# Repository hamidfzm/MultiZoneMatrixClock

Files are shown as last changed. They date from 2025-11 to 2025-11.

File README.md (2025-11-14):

# Multi-Zone Matrix Clock

A WiFi-enabled LED matrix clock for ESP8266 that displays time from multiple timezones. Features automatic NTP synchronization, DST handling, and a web-based configuration interface.

 

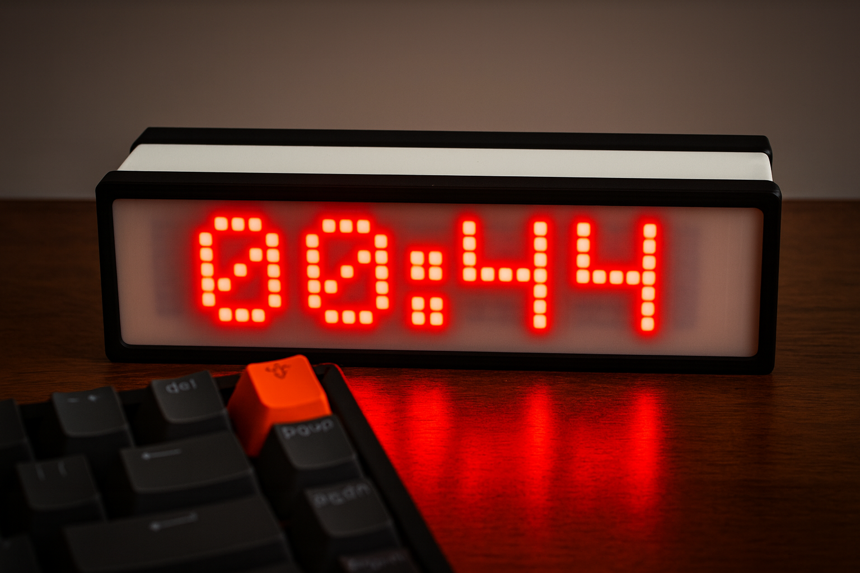
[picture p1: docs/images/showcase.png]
Showcase


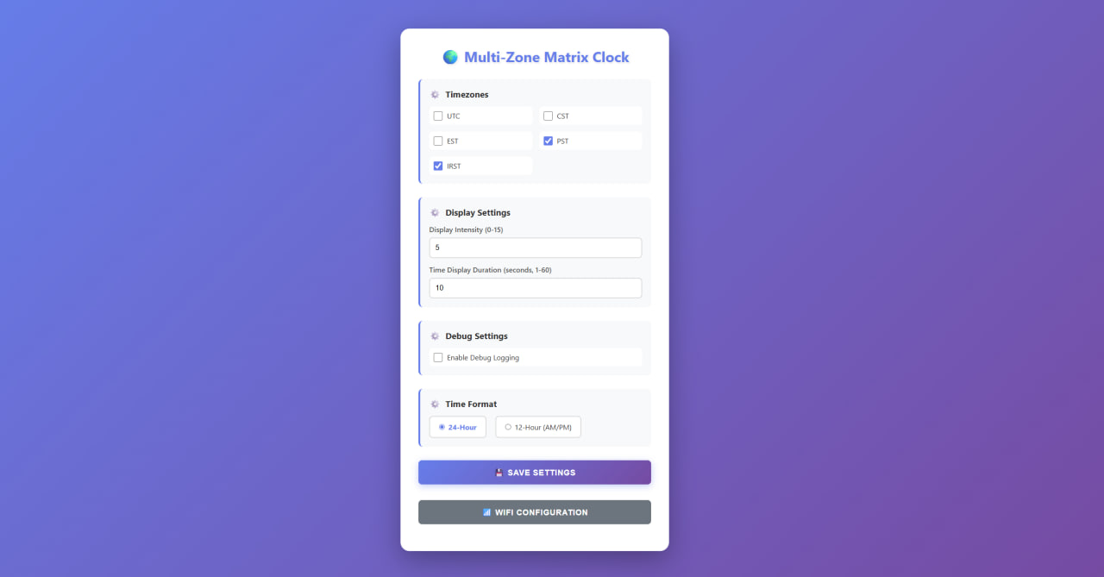
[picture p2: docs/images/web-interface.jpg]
Web Interface


## Features

- 🌍 **Multiple Timezone Support**: Display time from up to 6 different timezones (UTC, CST, EST, PST, IRST, and more)
- ⏰ **Automatic Time Sync**: NTP synchronization ensures accurate time
- 🌅 **DST Handling**: Automatic Daylight Saving Time adjustments for US timezones
- 📱 **Web Configuration**: Easy-to-use web interface for settings
- 🔌 **WiFi Manager**: Automatic WiFi configuration portal on first boot
- 🎨 **Customizable Display**: Adjustable brightness and 12/24-hour format
- 📺 **Animated Display**: Smooth scrolling animations for timezone names and time
- 💾 **Persistent Settings**: Settings saved to EEPROM

## Hardware Requirements

- **ESP8266** (NodeMCU, Wemos D1 Mini, or similar)
- **MAX7219 LED Matrix Display** (4 modules, FC16 hardware type)
- **Jumper wires** for connections
- **5V power supply** (USB or external adapter)

### Pin Connections

| ESP8266 Pin | MAX7219 Pin | Description |
|---|---|---|
| D5 | CLK | Clock |
| D7 | DIN | Data In |
| D8 | CS | Chip Select |
| 5V | VCC | Power |
| GND | GND | Ground |

> **Note**: The pin definitions can be modified in `config.h` if needed.

## 3D Printing

This project includes 3MF files for 3D printing the enclosure and mounting components. All files are optimized for **Bambu Lab A1 Mini** and are located in the `stl/` directory.

### Available 3MF Files

| File | Description |
|---|---|
| `FRONT.3mf` | Front panel/enclosure |
| `FRONT Wemos D1 Mini.3mf` | Front panel with Wemos D1 Mini mounting |
| `BACK.3mf` | Back panel/enclosure |
| `FRAME FRONT.3mf` | Front frame component |
| `FRAME BACK.3mf` | Back frame component |
| `2 x MATRIX HOLDER.3mf` | Matrix display holder (print 2x) |

### Printing Instructions for Bambu Lab A1 Mini

1. **Open files in Bambu Studio** (or compatible slicer)
2. **Recommended settings**:
   - **Layer height**: 0.2mm (standard quality) or 0.16mm (fine quality)
   - **Infill**: 15-20% (sufficient for structural integrity)
   - **Supports**: Enable if needed (check model orientation)
   - **Material**: PLA or PETG recommended
3. **Print order**:
   - Start with the frame components (`FRAME FRONT.3mf`, `FRAME BACK.3mf`)
   - Print the front and back panels
   - Print 2x of the matrix holder
4. **Assembly**: Follow the component names to assemble the enclosure

### Notes

- All files are provided in 3MF format for easy import into Bambu Studio
- The models are designed to fit standard MAX7219 8x8 LED matrix modules
- Ensure proper clearance for the ESP8266 board and wiring
- You may need to adjust print settings based on your specific material and preferences

## Software Requirements

### Arduino IDE Libraries

Install the following libraries via Arduino IDE Library Manager:

1. **ESP8266WiFi** (included with ESP8266 board support)
2. **WiFiManager** by tzapu - [GitHub](https://github.com/tzapu/WiFiManager)
3. **MD_Parola** by majicDesigns - [GitHub](https://github.com/MajicDesigns/MD_Parola)
4. **MD_MAX72XX** by majicDesigns - [GitHub](https://github.com/MajicDesigns/MD_MAX72XX)
5. **NTPClient** by Fabrice Weinberg - [GitHub](https://github.com/arduino-libraries/NTPClient)
6. **WiFiUdp** (included with ESP8266 board support)
7. **EEPROM** (included with ESP8266 board support)

### Arduino IDE Setup

1. Install **Arduino IDE** (1.8.x or newer)
2. Add ESP8266 board support:
   - Go to `File` → `Preferences`
   - Add to Additional Board Manager URLs: `http://arduino.esp8266.com/stable/package_esp8266com_index.json`
   - Go to `Tools` → `Board` → `Boards Manager`
   - Search for "ESP8266" and install
3. Select your board: `Tools` → `Board` → `ESP8266 Boards` → `NodeMCU 1.0 (ESP-12E Module)` (or your specific board)
4. Set upload speed to `115200` in `Tools` → `Upload Speed`

## Installation

1. **Clone or download** this repository
2. **Open** `MultiZoneMatrixClock.ino` in Arduino IDE
3. **Install required libraries** (see Software Requirements above)
4. **Connect your hardware** according to the pin connections table
5. **Select your ESP8266 board** and COM port in Arduino IDE
6. **Upload** the sketch to your ESP8266

## First Time Setup

1. **Power on** the ESP8266
2. **Connect to WiFi**: The device will create a WiFi access point named `MultiZoneClock`
3. **Connect** to this network with your phone/computer
4. **Configure WiFi**: A portal will automatically open (or navigate to `192.168.4.1`)
5. **Enter your WiFi credentials** and connect
6. **Note the IP address** displayed in Serial Monitor (or check your router's connected devices)
7. **Access the web interface** by navigating to the IP address in your browser

## Configuration

### Web Interface

Access the web configuration interface by navigating to your ESP8266's IP address in a web browser.

**Settings available:**
- **Timezones**: Enable/disable which timezones to display
- **Display Intensity**: Adjust brightness (0-15)
- **Time Format**: Choose between 12-hour (AM/PM) or 24-hour format
- **WiFi Configuration**: Reconfigure WiFi connection

### Default Settings

- **Enabled Timezones**: EST, IRST
- **Display Intensity**: 5
- **Time Format**: 24-hour
- **Time Display Duration**: 10 seconds per timezone

### Manual Configuration

You can modify default settings in the code:

- **Timezones**: Edit `timezone.cpp` to add/modify timezones
- **Hardware pins**: Edit `config.h` to change pin assignments
- **Display settings**: Edit `config.h` for timing and display parameters

## Usage

### Display Behavior

- **Single Timezone Mode**: If only one timezone is enabled, the clock displays time statically with a blinking colon
- **Multiple Timezone Mode**: If multiple timezones are enabled:
  1. Timezone name scrolls up
  2. Brief pause
  3. Time scrolls in from left
  4. Time scrolls out to right
  5. Repeats for next enabled timezone

### Time Synchronization

- The clock automatically syncs with NTP servers (`pool.ntp.org`)
- Sync occurs periodically to maintain accuracy
- DST is automatically calculated and applied for US timezones

## Project Structure

```
MultiZoneMatrixClock/
├── MultiZoneMatrixClock.ino  # Main Arduino sketch
├── config.h                   # Configuration constants and settings structure
├── display.h                  # Display manager header
├── display.cpp                # Display manager implementation
├── timezone.h                  # Timezone manager header
├── timezone.cpp                # Timezone manager implementation
├── webserver.h                 # Web server manager header
├── webserver.cpp               # Web server manager implementation
├── stl/                        # 3D printing files (3MF format)
│   ├── FRONT.3mf
│   ├── FRONT Wemos D1 Mini.3mf
│   ├── BACK.3mf
│   ├── FRAME FRONT.3mf
│   ├── FRAME BACK.3mf
│   └── 2 x MATRIX HOLDER.3mf
└── README.md                   # This file
```

## Troubleshooting

### WiFi Connection Issues

- **Can't connect to AP**: Reset the device and try again
- **Portal doesn't open**: Manually navigate to `192.168.4.1`
- **Can't find device IP**: Check Serial Monitor output or your router's device list

### Display Issues

- **No display**: Check wiring connections, especially power and ground
- **Garbled text**: Verify pin connections match `config.h`
- **Too dim/bright**: Adjust intensity in web interface (0-15)

### Time Issues

- **Wrong time**: Ensure WiFi is connected and NTP sync is working
- **DST not working**: Check that timezone uses DST in `timezone.cpp`
- **Timezone offset wrong**: Verify timezone offset in `timezone.cpp`

### Serial Monitor

Enable Serial Monitor at `115200` baud to see debug information:
- WiFi connection status
- IP address
- NTP sync status
- Display state changes

## Customization

### Adding New Timezones

Edit `timezone.cpp`:

```cpp
// Add to timezones array
timezones[5] = {"TZNAME", offset_seconds, uses_dst};
```

Update `TZ_COUNT` in `config.h` if adding more than 6 timezones.

### Changing Display Hardware

Modify `config.h`:
- `HARDWARE_TYPE`: Change if using different MAX7219 module type
- `MAX_DEVICES`: Number of matrix modules
- Pin definitions: `CLK_PIN`, `DATA_PIN`, `CS_PIN`

## Technical Details

- **MCU**: ESP8266 (80MHz, 4MB Flash)
- **Display**: MAX7219 8x8 LED Matrix (4 modules = 32x8 display)
- **Protocol**: SPI for display communication
- **Storage**: EEPROM for settings persistence
- **Network**: WiFi 802.11 b/g/n
- **Time Protocol**: NTP (Network Time Protocol)

## License

This project is open source. Feel free to modify and distribute.

## Contributing

Contributions are welcome! Please feel free to submit a Pull Request.

## Acknowledgments

- Built with Arduino IDE and ESP8266
- Uses excellent libraries from the Arduino community
- Inspired by the need for a simple, multi-timezone clock

## Support

For issues, questions, or contributions, please open an issue on GitHub.

---

**Enjoy your Multi-Zone Matrix Clock!** ⏰🌍

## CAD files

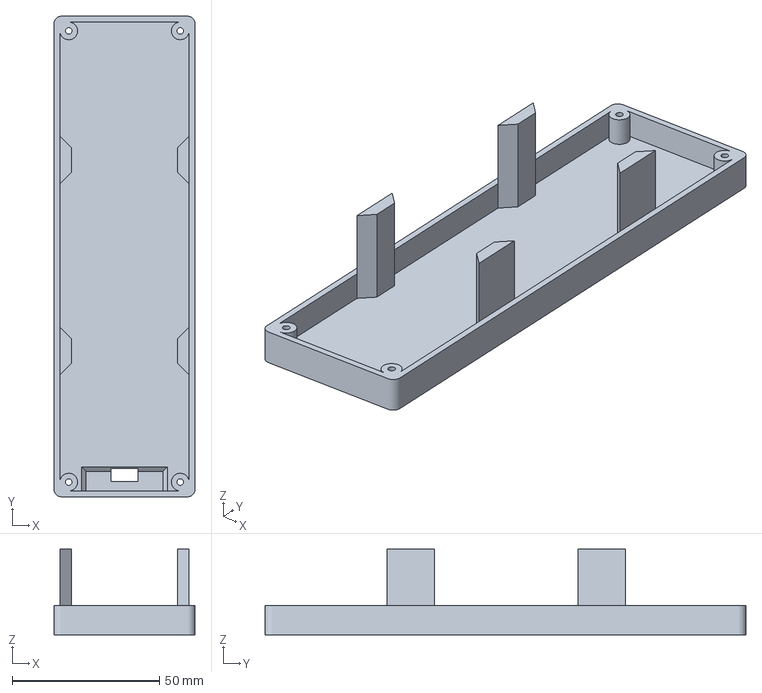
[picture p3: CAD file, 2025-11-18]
stl/BACK Wemos D1 Mini.3mf
47.8 x 162.9 x 29.0 mm

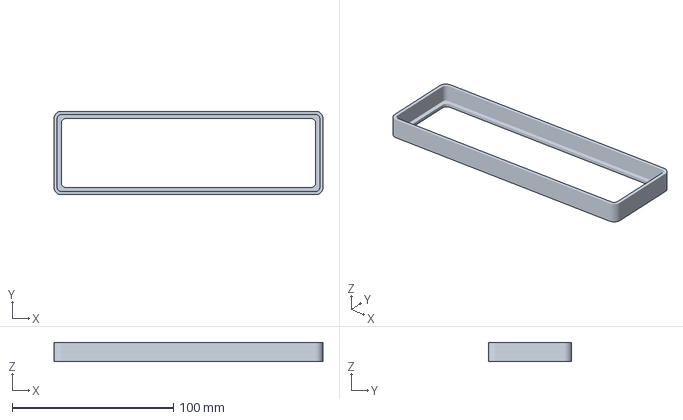
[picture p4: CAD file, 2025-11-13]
stl/FRAME FRONT.3mf
166.9 x 51.8 x 12.0 mm

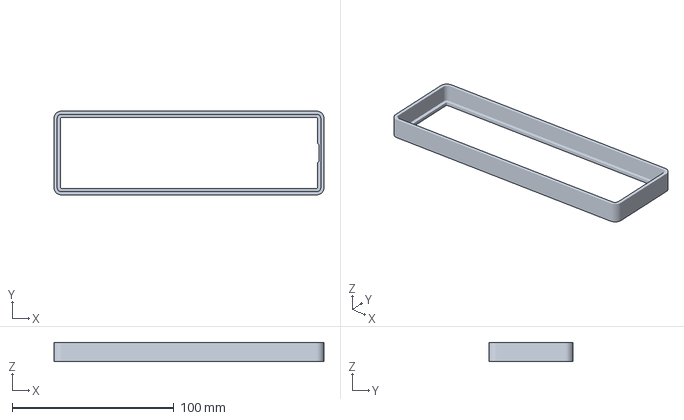
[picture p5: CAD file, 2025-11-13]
stl/FRAME BACK.3mf
166.9 x 51.8 x 12.0 mm

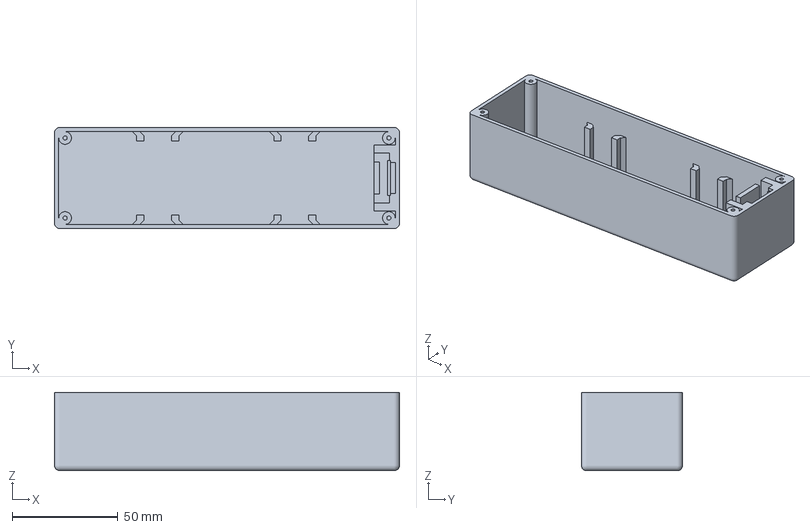
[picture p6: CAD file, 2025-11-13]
stl/FRONT.3mf
162.9 x 47.8 x 37.0 mm

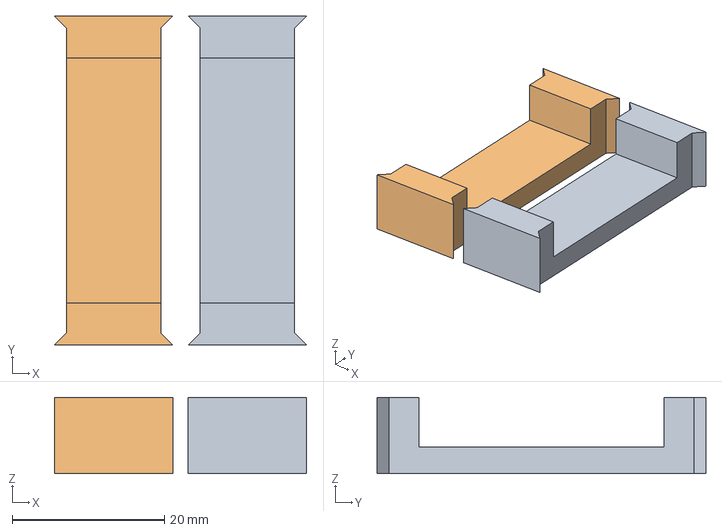
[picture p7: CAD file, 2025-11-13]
stl/2 x MATRIX HOLDER.3mf
33.1 x 43.2 x 10.0 mm
MATRIX HOLDER x 2

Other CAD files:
stl/BACK.3mf
stl/FRONT Wemos D1 Mini.3mf

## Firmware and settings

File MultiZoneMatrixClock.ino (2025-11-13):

#include <ESP8266WiFi.h>
#include <WiFiManager.h>
#include <ESP8266WebServer.h>
#include <WiFiUdp.h>
#include <NTPClient.h>
#include <EEPROM.h>
#include <time.h>

#include "config.h"
#include "timezone.h"
#include "display.h"
#include "webserver.h"

// Global objects
WiFiUDP ntpUDP;
NTPClient timeClient(ntpUDP, "pool.ntp.org");
ESP8266WebServer server(80);

TimezoneManager tzManager;
DisplayManager displayManager;
Settings settings;
WebServerManager webManager(&server, &tzManager, &settings, &displayManager);

void saveSettings() {
  settings.magic = EEPROM_MAGIC;
  for (int i = 0; i < TZ_COUNT; i++) {
    settings.enabled[i] = tzManager.tzEnabled[i] ? 1 : 0;
  }
  EEPROM.put(0, settings);
  EEPROM.commit();
}

void loadSettings() {
  EEPROM.get(0, settings);
  if (settings.magic != EEPROM_MAGIC) {
    // Default settings
    settings.intensity = 5;
    settings.use12Hour = 0;
    settings.debugEnabled = 0;
    settings.timeDisplayDuration = 10; // Default 10 seconds
    for (int i = 0; i < TZ_COUNT; i++) {
      settings.enabled[i] = tzManager.tzEnabled[i] ? 1 : 0;
    }
    saveSettings();
  } else {
    // Load enabled timezones from EEPROM
    for (int i = 0; i < TZ_COUNT; i++) {
      tzManager.tzEnabled[i] = settings.enabled[i] != 0;
    }
    // Initialize defaults for new fields if they're 0 (first time loading after update)
    if (settings.timeDisplayDuration == 0) {
      settings.timeDisplayDuration = 10;
    }
  }
  // Update display manager with time display duration
  displayManager.setTimeDisplayDuration(settings.timeDisplayDuration * 1000); // Convert to milliseconds
}

String getShortTime() {
  String full = timeClient.getFormattedTime(); // HH:MM:SS
  String hh = full.substring(0, 2);
  String mm = full.substring(3, 5);
  int hour = hh.toInt();
  int minute = mm.toInt();
  
  if (settings.use12Hour) {
    bool isPM = hour >= 12;
    hour = hour % 12;
    if (hour == 0) hour = 12;
    // Format with zero padding
    String hourStr = hour < 10 ? "0" + String(hour) : String(hour);
    String minuteStr = minute < 10 ? "0" + String(minute) : String(minute);
    return hourStr + ":" + minuteStr + (isPM ? " PM" : " AM");
  } else {
    // Already padded from getFormattedTime, but ensure it's correct
    return hh + ":" + mm;
  }
}

void setup() {
  Serial.begin(115200);
  delay(1000);
  
  // Initialize EEPROM
  EEPROM.begin(EEPROM_SIZE);
  
  // Initialize timezone manager
  tzManager.init();
  
  // Load settings from EEPROM (this will initialize debug flag)
  loadSettings();
  
  // Only log if debug is enabled
  if (settings.debugEnabled) {
    Serial.println("Multi-Zone Matrix Clock Starting...");
  }
  
  // Initialize display
  displayManager.begin(settings.intensity);
  displayManager.setShowTimezone(tzManager.getEnabledCount() > 1);
  
  // Connect to WiFi
  WiFiManager wm;
  wm.autoConnect("MultiZoneClock");
  
  if (settings.debugEnabled) {
    Serial.print("Connected! IP address: ");
    Serial.println(WiFi.localIP());
  }
  
  // Initialize NTP client
  timeClient.begin();
  
  // Find first enabled timezone
  int firstTZ = tzManager.nextEnabledTZ(-1);
  if (firstTZ >= 0) {
    displayManager.setCurrentTZ(firstTZ);
    long offset = tzManager.getCurrentOffset(firstTZ);
    timeClient.setTimeOffset(offset);
  }
  
  // Initialize web server
  webManager.begin();
  
  // Start with first timezone display
  int enabledCount = tzManager.getEnabledCount();
  if (enabledCount > 0) {
    if (enabledCount > 1 && displayManager.shouldShowTimezone()) {
      displayManager.setState(SHOW_TZ_SCROLL);
      String tzName = String(tzManager.getTimezoneName(firstTZ));
      displayManager.setTimezoneName(tzName); // This will start the scroll
    } else {
      // Single timezone mode - go straight to time
      String timeStr = getShortTime();
      displayManager.setTimeString(timeStr);
      displayManager.setState(SHOW_TIME_STATIC);
    }
  }
  
  if (settings.debugEnabled) {
    Serial.println("Setup complete!");
  }
}

void loop() {
  server.handleClient();
  
  // Update NTP client periodically (it's smart enough to only sync when needed)
  static unsigned long lastNTPUpdate = 0;
  if (millis() - lastNTPUpdate >= NTP_UPDATE_INTERVAL) {
    timeClient.update();
    lastNTPUpdate = millis();
  }
  
  // Update time offset only when timezone changes (for DST and timezone switching)
  static int lastTZ = -1;
  int currentTZ = displayManager.getCurrentTZ();
  if (currentTZ != lastTZ) {
    long currentOffset = tzManager.getCurrentOffset(currentTZ);
    timeClient.setTimeOffset(currentOffset);
    lastTZ = currentTZ;
  }
  
  DisplayState state = displayManager.getState();
  
  switch (state) {
    case SHOW_TZ_SCROLL:
      displayManager.update();
      if (displayManager.getState() == SHOW_TZ_WAIT) {
        // Prepare time string
        String timeStr = getShortTime();
        displayManager.setTimeString(timeStr);
      }
      break;
      
    case SHOW_TZ_WAIT:
      displayManager.update();
      break;
      
    case SHOW_TIME_LTR:
      displayManager.update();
      break;
      
    case SHOW_TIME_RTL:
      displayManager.update();
      if (displayManager.getState() == SHOW_TZ_SCROLL) {
        // Move to next timezone
        int nextTZ = tzManager.nextEnabledTZ(currentTZ);
        displayManager.setCurrentTZ(nextTZ);
        
        // Update timezone display setting based on count
        int enabledCount = tzManager.getEnabledCount();
        displayManager.setShowTimezone(enabledCount > 1);
        
        if (displayManager.shouldShowTimezone()) {
          String tzName = String(tzManager.getTimezoneName(nextTZ));
          displayManager.setTimezoneName(tzName);
        } else {
          // Single timezone mode - skip timezone name, go straight to time
          displayManager.setTimezoneName("");
          String timeStr = getShortTime();
          displayManager.setTimeString(timeStr);
          displayManager.setState(SHOW_TZ_WAIT);
        }
      }
      break;
      
    case SHOW_TIME_STATIC: {
      displayManager.update();
      // Update time string periodically for single timezone mode
      int enabledCount = tzManager.getEnabledCount();
      if (enabledCount == 1) {
        // Single timezone mode - just update time every second
        static unsigned long lastTimeUpdate = 0;
        if (millis() - lastTimeUpdate >= 1000) {
          String timeStr = getShortTime();
          displayManager.setTimeString(timeStr);
          displayManager.setState(SHOW_TIME_STATIC); // Reset the state to update display
          lastTimeUpdate = millis();
        }
      } else if (millis() - displayManager.getWaitStart() >= (unsigned long)settings.timeDisplayDuration * 1000) {
        // Multiple timezones - move to next timezone
        int nextTZ = tzManager.nextEnabledTZ(currentTZ);
        displayManager.setCurrentTZ(nextTZ);
        
        displayManager.setState(SHOW_TZ_SCROLL);
        String tzName = String(tzManager.getTimezoneName(nextTZ));
        displayManager.setTimezoneName(tzName); // This will start the scroll
      }
      break;
    }
  }
  
  // Small delay to prevent overwhelming the system
  delay(10);
}

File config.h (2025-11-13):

#ifndef CONFIG_H
#define CONFIG_H

#include <stdint.h>

// Hardware configuration
#define HARDWARE_TYPE MD_MAX72XX::FC16_HW
#define MAX_DEVICES 4
#define CLK_PIN   D5
#define DATA_PIN  D7
#define CS_PIN    D8

// EEPROM configuration
#define EEPROM_SIZE 64
#define EEPROM_MAGIC 0x42

// Display timing
const unsigned long WAIT_DURATION = 2000;
const unsigned long STATIC_TIME_DURATION_DEFAULT = 10000; // Default 10 seconds in ms
const unsigned long BLINK_INTERVAL = 500; // Colon blink interval in ms
const unsigned long NTP_UPDATE_INTERVAL = 1000; // Update NTP client every second

// Timezone count
const int TZ_COUNT = 6; // UTC, CST, EST, PST, IRST, and one extra slot

// Settings structure
struct Settings {
  uint8_t magic;
  uint8_t enabled[TZ_COUNT];
  uint8_t intensity;
  uint8_t use12Hour;
  uint8_t debugEnabled;
  uint16_t timeDisplayDuration; // Duration in seconds (default 10)
};

#endif

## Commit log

2025-11-13 docs: update README.md with 3D printing section and add 3MF files for enclosure components
    [2 x MATRIX HOLDER.3mf, BACK.3mf, FRAME BACK.3mf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]
2025-11-18 feat: add 3MF file for Wemos D1 Mini back enclosure component
    [BACK Wemos D1 Mini.3mf]
